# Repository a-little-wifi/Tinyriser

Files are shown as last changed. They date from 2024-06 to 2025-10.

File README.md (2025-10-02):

# TinyRiser
Cooler/cuter riser for Lenovo 8th/9th gen Tiny5 PCs

Exposes the x8 and x4 PCIe links in the riser slot, in the form of a PCIe x16 slot and an m.2 slot.

The x8 link comes from the CPU and was meant for GPU equipped models, while the x4 link comes from the PCH and was meant for the Thunderbolt and NIC equipped models. Lenovo made two different risers for these configurations, only using one link at a time, but this riser gives you both PCIe links at once! The two links are completely independent and are able to function at the same time.

Using this riser, you can install a low profile PCIe card just as you can with the stock risers, and add an extra M.2 NVMe SSD in addition to the onboard ones. The SSD is tucked away near the front of the machine, plugged into a right angle M-key M.2 slot that holds the SSD firmly in place. Due to an unfortunate non-removable standoff placement on the motherboard, only 2230, 2242 and 2260 size SSDs fit comfortably. It is possible to get a 2280 drive to fit if you try hard enough, but the fit will be suboptimal.

Doesn't require any modifications to the motherboard, just works plug and play (no bifurcation/lane reversal).

I've successfully tested this riser on my own M720q where it works 100% perfectly with x1, x4, x8 and x16 cards, and it will work just as well on the other machines that share this motherboard, the M920q, M920x and P330 Tiny.

Note that the M.2 slot only supports PCIe NVMe M-key or B+M-key drives, not SATA ones.

The v2 design includes a fan header that can be used in multiple ways:

- 12V no PWM
- 12V with PWM
- Voltage controlled speed

The last 2 modes require some kind of fan controller module plugged into the provided header. This has not been designed yet, but the possibility exists.

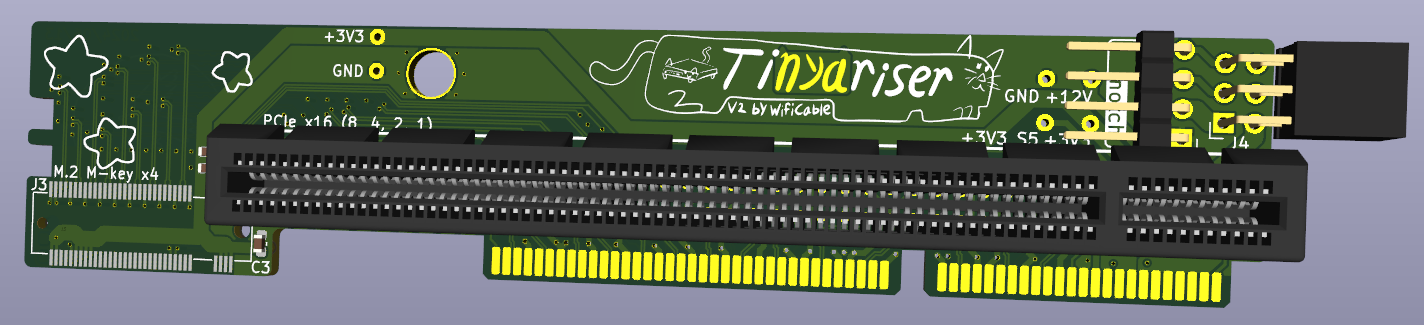
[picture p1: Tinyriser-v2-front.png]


> Front side render of the PCB. I don't have a 3D model for the m.2 slot but you can see the footprint for it

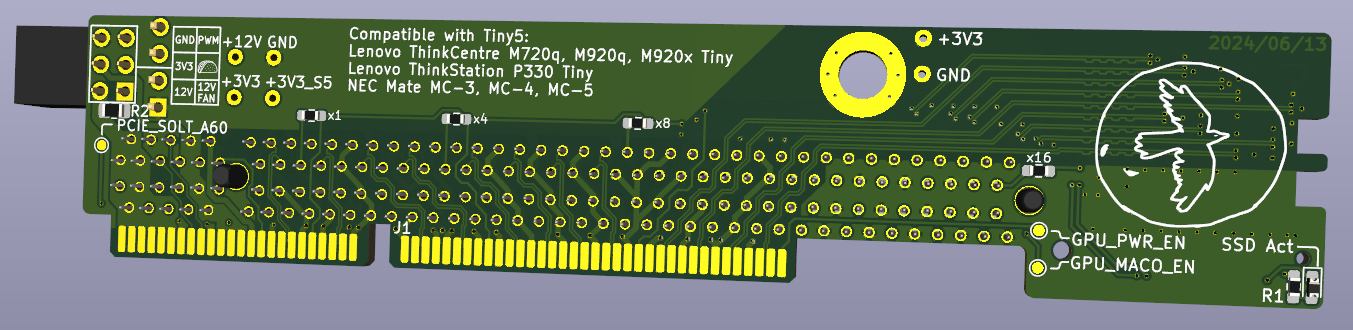
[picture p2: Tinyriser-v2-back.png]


> Back side render of the PCB.

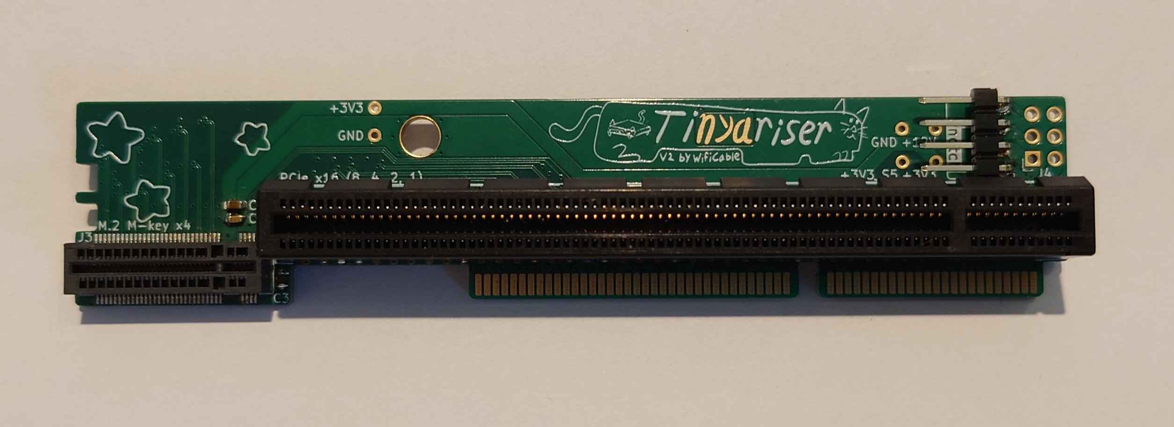
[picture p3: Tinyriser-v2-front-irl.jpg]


> Front of it but in real life

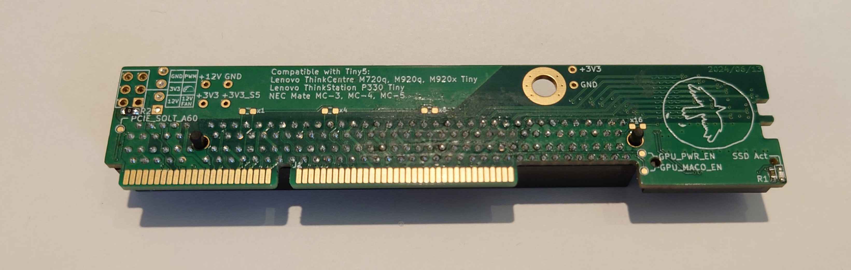
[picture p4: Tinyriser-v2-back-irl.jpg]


> Back of it but also in real life

Compatible with M720q, M920q, M920x and P330 Tiny, as well as the NEC rebranded versions of those.  
**Don't stick it in an M910x or P320 Tiny, it will physically fit but the pinout is not compatible.**

Currently in version 2.1

## Parts list:
| part | model | link |
|---|---|---|
| PCIe slot | UMAX 3183-10203P1T | https://www.lcsc.com/product-detail/Card-Edge-Connectors_UMAX-3183-10203P1T_C404116.html |
| Vertical M-key slot | Lotes APCI0110-P001A | (available on aliexpress) |
| Screwpost | YIYUAN SMTSOM340BTR  | https://www.lcsc.com/product-detail/Other-nuts_YIYUAN-SMTSOM340BTR_C5301786.html |

## JLC PCB ordering details:

Please use the files from the v2.1 release, the main repo might be in the middle of version changes

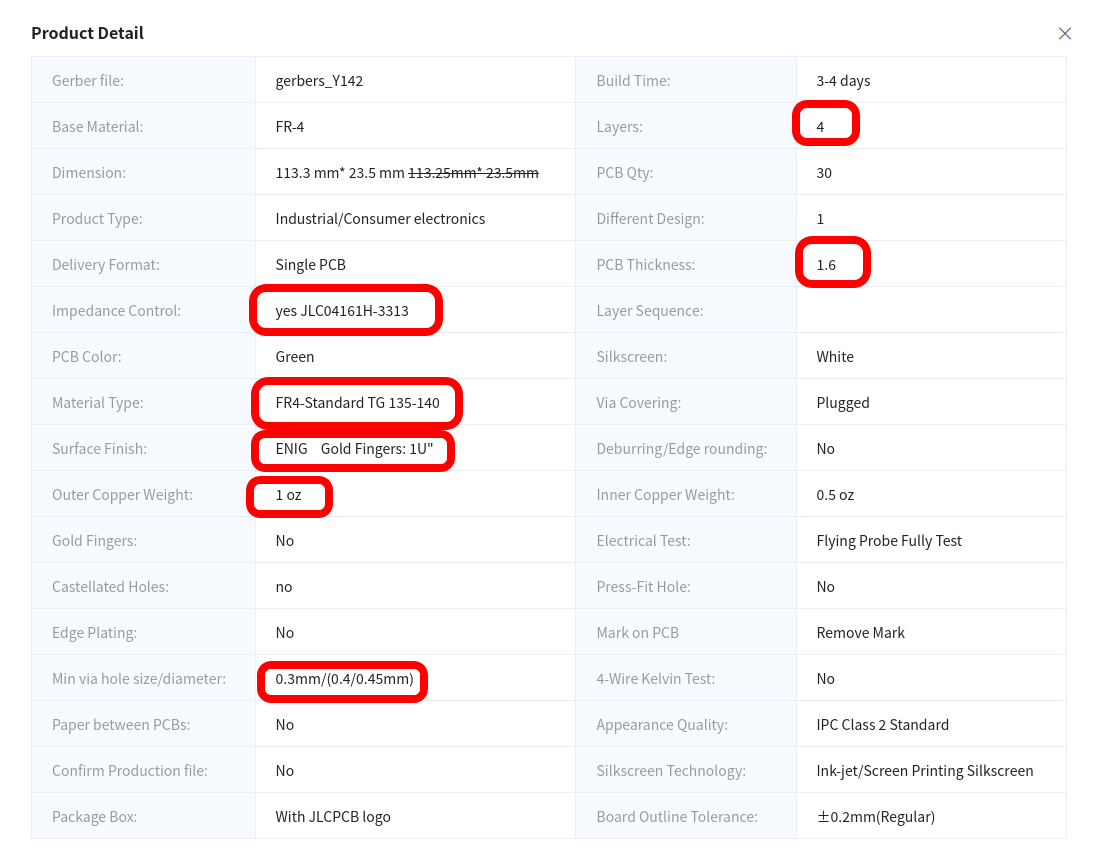
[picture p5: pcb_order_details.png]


> Screenshot of the JLC PCB order settings used for TinyRiser

https://github.com/a-little-wifi/Tinyriser/assets/139929586/086969f3-38e6-4d3a-b0c4-e65df9add474  
> unmute it

# Attribution
If you distribute this design or use this design to create a derivative design, you must keep attribution to this original design, in addition to following the terms in the license

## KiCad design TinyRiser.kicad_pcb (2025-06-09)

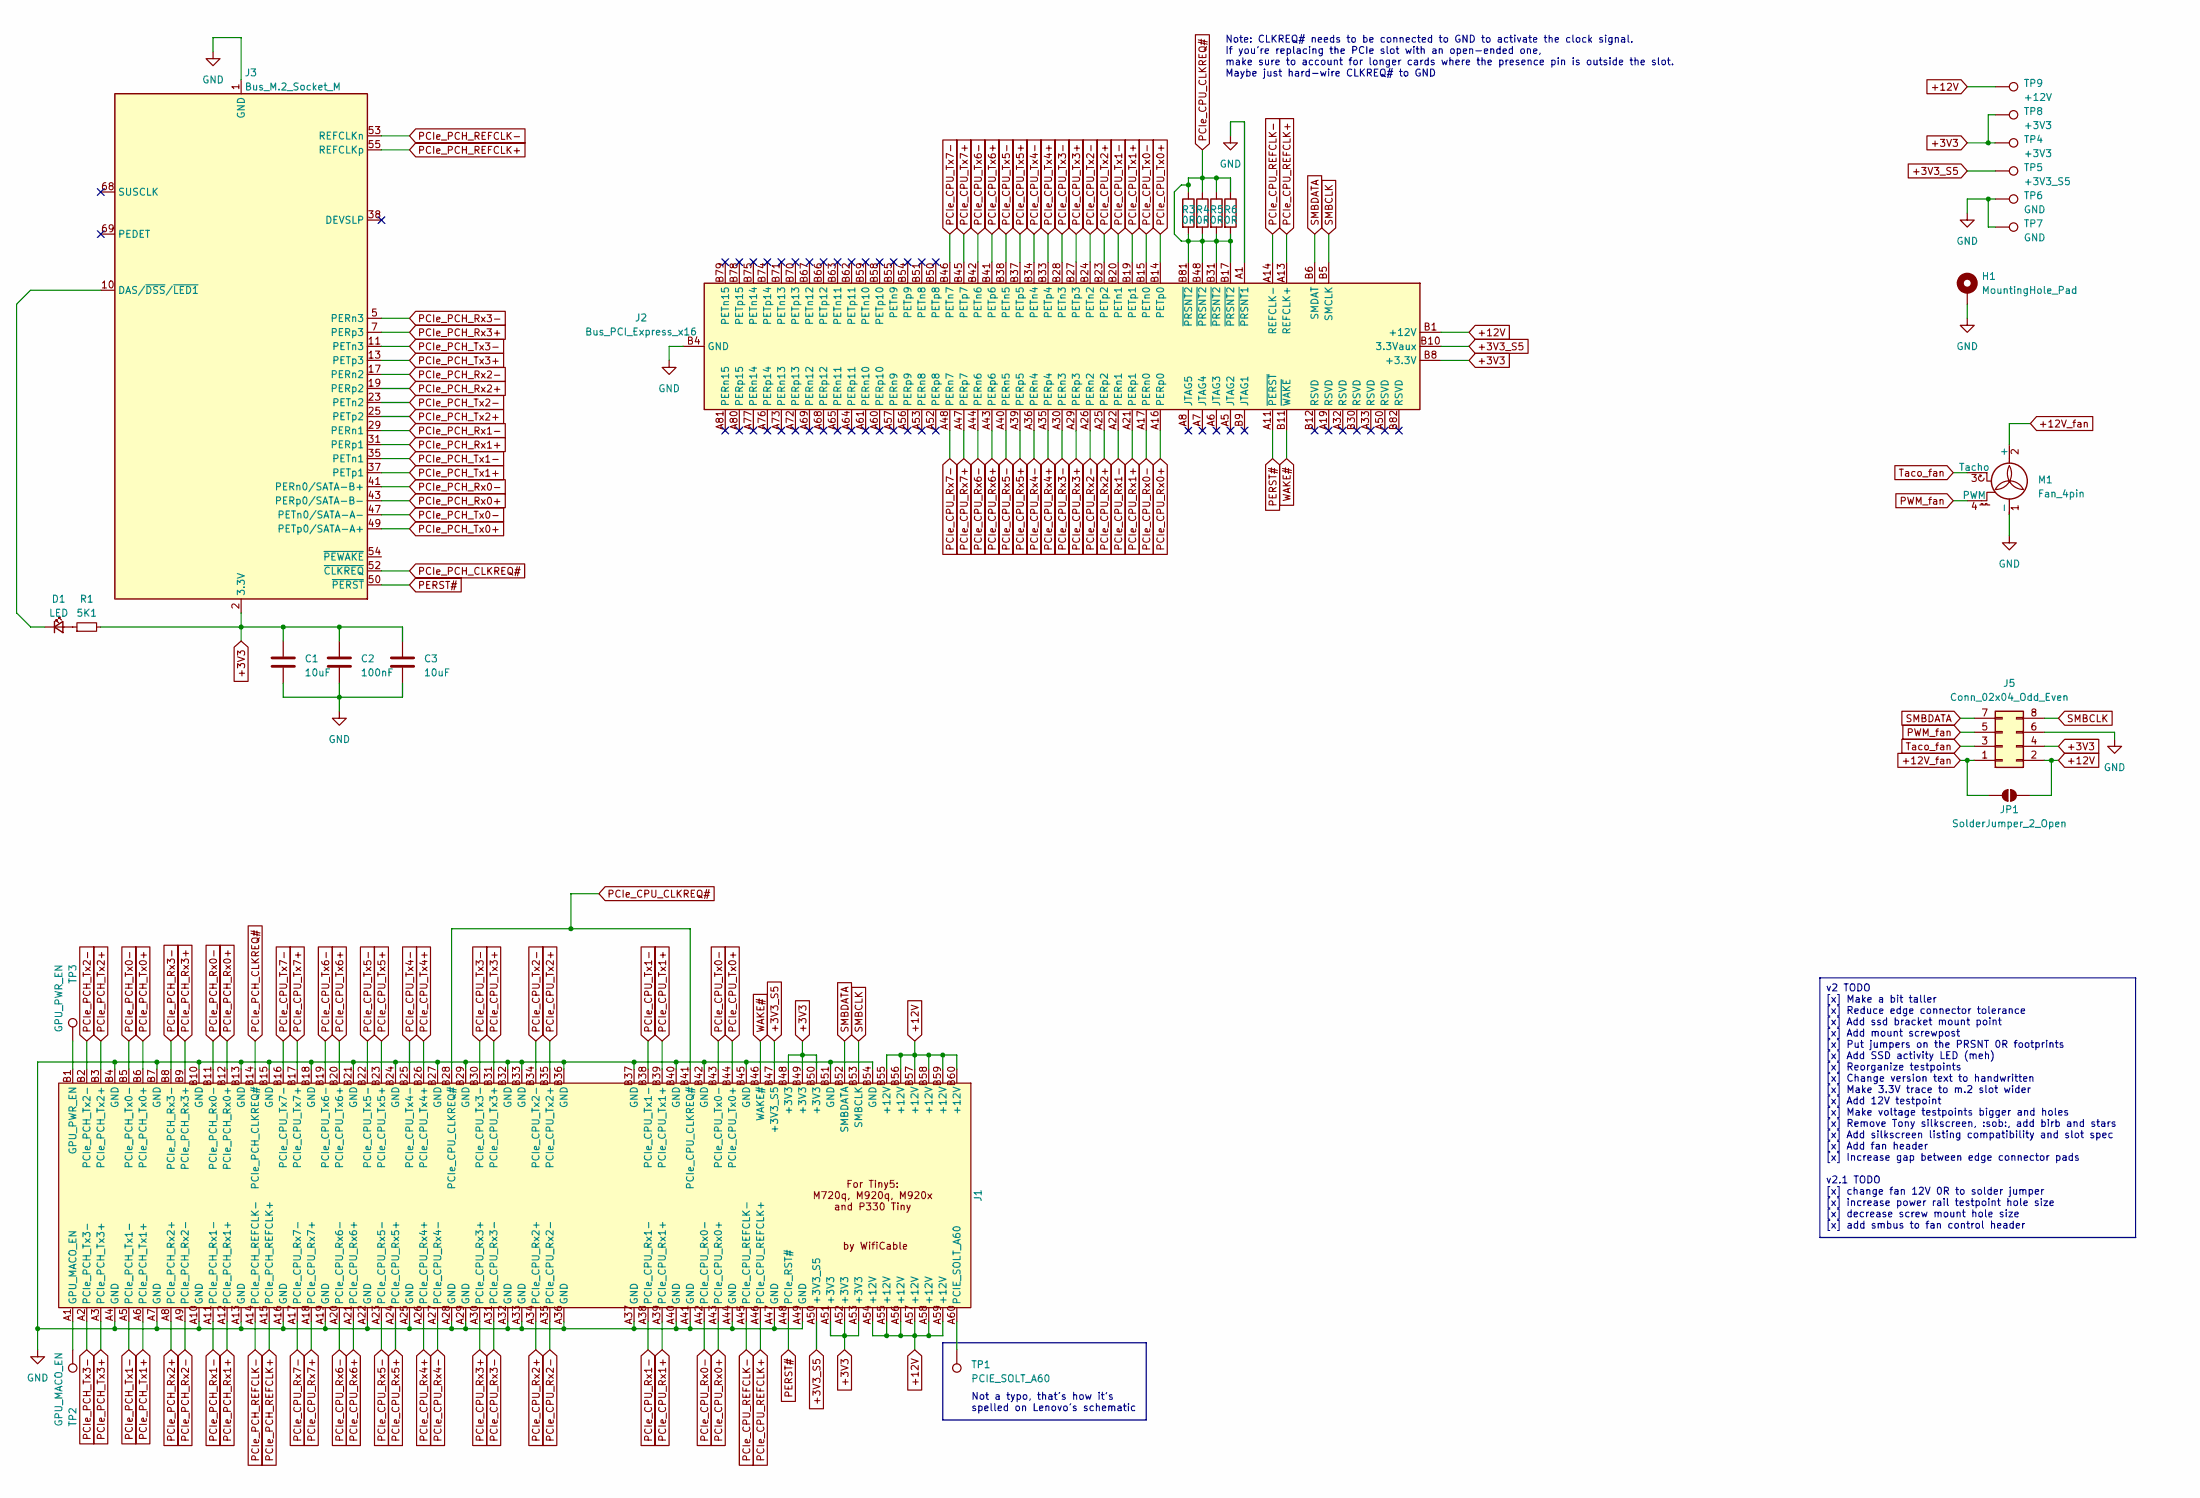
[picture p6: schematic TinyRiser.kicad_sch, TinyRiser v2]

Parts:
C1, C3: 10uF; C_0603_1608Metric
C2: 100nF; C_0603_1608Metric
D1: LED; D_0603_1608Metric_Pad1.05x0.95mm_HandSolder
H1: MountingHole_Pad; MountingHole_4.3mm_M4_ISO7380_Pad_TopOnly
J1: TinyRiser
J2: Bus_PCI_Express_x16; PCIe_x16_tht
J3: Bus_M.2_Socket_M; M.2_NGFF_KeyM_H5.3_Vertical
J5: Conn_02x04_Odd_Even; PinSocket_2x04_P2.54mm_Horizontal
JP1: SolderJumper_2_Open; SolderJumper-2_P1.3mm_Open_TrianglePad1.0x1.5mm
M1: Fan_4pin; PinHeader_1x04_P2.54mm_Horizontal
R1: 5K1; R_0603_1608Metric_Pad0.98x0.95mm_HandSolder
R3, R4, R5, R6: 0R; R_0603_1608Metric_Pad0.98x0.95mm_HandSolder
TP1: PCIE_SOLT_A60; TestPoint_Pad_D1.0mm
TP2: GPU_MACO_EN; TestPoint_Pad_D1.0mm
TP3: GPU_PWR_EN; TestPoint_Pad_D1.0mm
TP4, TP8: +3V3; TestPoint_THTPad_D1.5mm_Drill0.7mm
TP5: +3V3_S5; TestPoint_THTPad_D1.5mm_Drill0.7mm
TP6, TP7: GND; TestPoint_THTPad_D1.5mm_Drill0.7mm
TP9: +12V; TestPoint_THTPad_D1.5mm_Drill0.7mm

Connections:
+3V3: C1.1, C2.1, C3.1, J1.A51 (+3V3), J1.A52 (+3V3), J1.A53 (+3V3), J1.B48 (+3V3), J1.B49 (+3V3), J1.B50 (+3V3), J2.A9 (+3.3V), J2.A10 (+3.3V), J2.B8 (+3.3V), J3.2 (3.3V), J3.4 (3.3V), J3.12 (3.3V), J3.14 (3.3V), J3.16 (3.3V), J3.18 (3.3V), J3.70 (3.3V), J3.72 (3.3V), J3.74 (3.3V), J5.4, R1.2, TP4.1, TP8.1
+3V3_S5: J1.A50 (+3V3_S5), J1.B47 (+3V3_S5), J2.B10 (3.3Vaux), TP5.1
+12V: J1.A54 (+12V), J1.A55 (+12V), J1.A56 (+12V), J1.A57 (+12V), J1.A58 (+12V), J1.A59 (+12V), J1.B55 (+12V), J1.B56 (+12V), J1.B57 (+12V), J1.B58 (+12V), J1.B59 (+12V), J1.B60 (+12V), J2.A2 (+12V), J2.A3 (+12V), J2.B1 (+12V), J2.B2 (+12V), J2.B3 (+12V), J5.2, JP1.2 (B), TP9.1
+12V_fan: J5.1, JP1.1 (A), M1.2 (+)
GND: C1.2, C2.2, C3.2, H1.1, J1.A4 (GND), J1.A7 (GND), J1.A10 (GND), J1.A13 (GND), J1.A16 (GND), J1.A19 (GND), J1.A22 (GND), J1.A25 (GND), J1.A28 (GND), J1.A29 (GND), J1.A32 (GND), J1.A33 (GND), J1.A36 (GND), J1.A37 (GND), J1.A40 (GND), J1.A41 (GND), J1.A44 (GND), J1.A47 (GND), J1.A49 (GND), J1.B4 (GND), J1.B7 (GND), J1.B10 (GND), J1.B13 (GND), J1.B15 (GND), J1.B18 (GND), J1.B21 (GND), J1.B24 (GND), J1.B27 (GND), J1.B29 (GND), J1.B32 (GND), J1.B33 (GND), J1.B36 (GND), J1.B37 (GND), J1.B40 (GND), J1.B42 (GND), J1.B45 (GND), J1.B51 (GND), J1.B54 (GND), J2.A1 (~PRSNT1), J2.A4 (GND), J2.A12 (GND), J2.A15 (GND), J2.A18 (GND), J2.A20 (GND), J2.A23 (GND), J2.A24 (GND), J2.A27 (GND), J2.A28 (GND), J2.A31 (GND), J2.A34 (GND), J2.A37 (GND), J2.A38 (GND), J2.A41 (GND), J2.A42 (GND), J2.A45 (GND), J2.A46 (GND), J2.A49 (GND), J2.A51 (GND), J2.A54 (GND), J2.A55 (GND), J2.A58 (GND), J2.A59 (GND), J2.A62 (GND), J2.A63 (GND), J2.A66 (GND), J2.A67 (GND), J2.A70 (GND), J2.A71 (GND), J2.A74 (GND), J2.A75 (GND), J2.A78 (GND), J2.A79 (GND), J2.A82 (GND), J2.B4 (GND), J2.B7 (GND), J2.B13 (GND), J2.B16 (GND), J2.B18 (GND), J2.B21 (GND), J2.B22 (GND), J2.B25 (GND), J2.B26 (GND), J2.B29 (GND), J2.B32 (GND), J2.B35 (GND), J2.B36 (GND), J2.B39 (GND), J2.B40 (GND), J2.B43 (GND), J2.B44 (GND), J2.B47 (GND), J2.B49 (GND), J2.B52 (GND), J2.B53 (GND), J2.B56 (GND), J2.B57 (GND), J2.B60 (GND), J2.B61 (GND), J2.B64 (GND), J2.B65 (GND), J2.B68 (GND), J2.B69 (GND), J2.B72 (GND), J2.B73 (GND), J2.B76 (GND), J2.B77 (GND), J2.B80 (GND), J3.1 (GND), J3.3 (GND), J3.9 (GND), J3.15 (GND), J3.21 (GND), J3.27 (GND), J3.33 (GND), J3.39 (GND), J3.45 (GND), J3.51 (GND), J3.57 (GND), J3.71 (GND), J3.73 (GND), J3.75 (GND), J5.6, M1.1 (-), TP6.1, TP7.1
unnamed: D1.2 (A), R1.1
unnamed: D1.1 (K), J3.10 (DAS/~DSS/~LED1)
unnamed: J1.A1 (GPU_MACO_EN), TP2.1
unnamed: J1.B1 (GPU_PWR_EN), TP3.1
unnamed: J1.A60 (PCIE_SOLT_A60), TP1.1
PCIe_CPU_CLKREQ#: J1.B28 (PCIe_CPU_CLKREQ#), J1.B41 (PCIe_CPU_CLKREQ#), J2.B17 (~PRSNT2), J2.B31 (~PRSNT2), J2.B48 (~PRSNT2), J2.B81 (~PRSNT2), R3.1, R3.2, R4.1, R4.2, R5.1, R5.2, R6.1, R6.2
PCIe_CPU_REFCLK+: J1.A46 (PCIe_CPU_REFCLK+), J2.A13 (REFCLK+)
PCIe_CPU_REFCLK-: J1.A45 (PCIe_CPU_REFCLK-), J2.A14 (REFCLK-)
PCIe_CPU_Rx0+: J1.A43 (PCIe_CPU_Rx0+), J2.A16 (PERp0)
PCIe_CPU_Rx0-: J1.A42 (PCIe_CPU_Rx0-), J2.A17 (PERn0)
PCIe_CPU_Rx1+: J1.A39 (PCIe_CPU_Rx1+), J2.A21 (PERp1)
PCIe_CPU_Rx1-: J1.A38 (PCIe_CPU_Rx1-), J2.A22 (PERn1)
PCIe_CPU_Rx2+: J1.A34 (PCIe_CPU_Rx2+), J2.A25 (PERp2)
PCIe_CPU_Rx2-: J1.A35 (PCIe_CPU_Rx2-), J2.A26 (PERn2)
PCIe_CPU_Rx3+: J1.A30 (PCIe_CPU_Rx3+), J2.A29 (PERp3)
PCIe_CPU_Rx3-: J1.A31 (PCIe_CPU_Rx3-), J2.A30 (PERn3)
PCIe_CPU_Rx4+: J1.A26 (PCIe_CPU_Rx4+), J2.A35 (PERp4)
PCIe_CPU_Rx4-: J1.A27 (PCIe_CPU_Rx4-), J2.A36 (PERn4)
PCIe_CPU_Rx5+: J1.A24 (PCIe_CPU_Rx5+), J2.A39 (PERp5)
PCIe_CPU_Rx5-: J1.A23 (PCIe_CPU_Rx5-), J2.A40 (PERn5)
PCIe_CPU_Rx6+: J1.A21 (PCIe_CPU_Rx6+), J2.A43 (PERp6)
PCIe_CPU_Rx6-: J1.A20 (PCIe_CPU_Rx6-), J2.A44 (PERn6)
PCIe_CPU_Rx7+: J1.A18 (PCIe_CPU_Rx7+), J2.A47 (PERp7)
PCIe_CPU_Rx7-: J1.A17 (PCIe_CPU_Rx7-), J2.A48 (PERn7)
PCIe_CPU_Tx0+: J1.B44 (PCIe_CPU_Tx0+), J2.B14 (PETp0)
PCIe_CPU_Tx0-: J1.B43 (PCIe_CPU_Tx0-), J2.B15 (PETn0)
PCIe_CPU_Tx1+: J1.B39 (PCIe_CPU_Tx1+), J2.B19 (PETp1)
PCIe_CPU_Tx1-: J1.B38 (PCIe_CPU_Tx1-), J2.B20 (PETn1)
PCIe_CPU_Tx2+: J1.B35 (PCIe_CPU_Tx2+), J2.B23 (PETp2)
PCIe_CPU_Tx2-: J1.B34 (PCIe_CPU_Tx2-), J2.B24 (PETn2)
PCIe_CPU_Tx3+: J1.B31 (PCIe_CPU_Tx3+), J2.B27 (PETp3)
PCIe_CPU_Tx3-: J1.B30 (PCIe_CPU_Tx3-), J2.B28 (PETn3)
PCIe_CPU_Tx4+: J1.B26 (PCIe_CPU_Tx4+), J2.B33 (PETp4)
PCIe_CPU_Tx4-: J1.B25 (PCIe_CPU_Tx4-), J2.B34 (PETn4)
PCIe_CPU_Tx5+: J1.B23 (PCIe_CPU_Tx5+), J2.B37 (PETp5)
PCIe_CPU_Tx5-: J1.B22 (PCIe_CPU_Tx5-), J2.B38 (PETn5)
PCIe_CPU_Tx6+: J1.B20 (PCIe_CPU_Tx6+), J2.B41 (PETp6)
PCIe_CPU_Tx6-: J1.B19 (PCIe_CPU_Tx6-), J2.B42 (PETn6)
PCIe_CPU_Tx7+: J1.B17 (PCIe_CPU_Tx7+), J2.B45 (PETp7)
PCIe_CPU_Tx7-: J1.B16 (PCIe_CPU_Tx7-), J2.B46 (PETn7)
PCIe_PCH_CLKREQ#: J1.B14 (PCIe_PCH_CLKREQ#), J3.52 (~CLKREQ)
PCIe_PCH_REFCLK+: J1.A15 (PCIe_PCH_REFCLK+), J3.55 (REFCLKp)
PCIe_PCH_REFCLK-: J1.A14 (PCIe_PCH_REFCLK-), J3.53 (REFCLKn)
PCIe_PCH_Rx0+: J1.B12 (PCIe_PCH_Rx0+), J3.43 (PERp0/SATA-B-)
PCIe_PCH_Rx0-: J1.B11 (PCIe_PCH_Rx0-), J3.41 (PERn0/SATA-B+)
PCIe_PCH_Rx1+: J1.A12 (PCIe_PCH_Rx1+), J3.31 (PERp1)
PCIe_PCH_Rx1-: J1.A11 (PCIe_PCH_Rx1-), J3.29 (PERn1)
PCIe_PCH_Rx2+: J1.A8 (PCIe_PCH_Rx2+), J3.19 (PERp2)
PCIe_PCH_Rx2-: J1.A9 (PCIe_PCH_Rx2-), J3.17 (PERn2)
PCIe_PCH_Rx3+: J1.B9 (PCIe_PCH_Rx3+), J3.7 (PERp3)
PCIe_PCH_Rx3-: J1.B8 (PCIe_PCH_Rx3-), J3.5 (PERn3)
PCIe_PCH_Tx0+: J1.B6 (PCIe_PCH_Tx0+), J3.49 (PETp0/SATA-A+)
PCIe_PCH_Tx0-: J1.B5 (PCIe_PCH_Tx0-), J3.47 (PETn0/SATA-A-)
PCIe_PCH_Tx1+: J1.A6 (PCIe_PCH_Tx1+), J3.37 (PETp1)
PCIe_PCH_Tx1-: J1.A5 (PCIe_PCH_Tx1-), J3.35 (PETn1)
PCIe_PCH_Tx2+: J1.B3 (PCIe_PCH_Tx2+), J3.25 (PETp2)
PCIe_PCH_Tx2-: J1.B2 (PCIe_PCH_Tx2-), J3.23 (PETn2)
PCIe_PCH_Tx3+: J1.A3 (PCIe_PCH_Tx3+), J3.13 (PETp3)
PCIe_PCH_Tx3-: J1.A2 (PCIe_PCH_Tx3-), J3.11 (PETn3)
PERST#: J1.A48 (PCIe_RST#), J2.A11 (~PERST), J3.50 (~PERST)
PWM_fan: J5.5, M1.4 (PWM)
SMBCLK: J1.B53 (SMBCLK), J2.B5 (SMCLK), J5.8
SMBDATA: J1.B52 (SMBDATA), J2.B6 (SMDAT), J5.7
Taco_fan: J5.3, M1.3 (Tacho)
WAKE#: J1.B46 (WAKE#), J2.B11 (~WAKE)

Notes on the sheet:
v2 TODO [x] Make a bit taller [x] Reduce edge connector tolerance [x] Add ssd bracket mount point [x] Add mount screwpost [x] Put jumpers on the PRSNT 0R footprints [x] Add SSD activity LED (meh) [x] Reorganize testpoints [x] Change version text to handwritten [x] Make 3.3V trace to m.2 slot wider 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
Not a typo, that's how it's spelled on Lenovo's schematic
Note: CLKREQ# needs to be connected to GND to activate the clock signal. If you're replacing the PCIe slot with an open-ended one, make sure to account for longer cards where the presence pin is outside the slot. Maybe just hard-wire CLKREQ# to GND

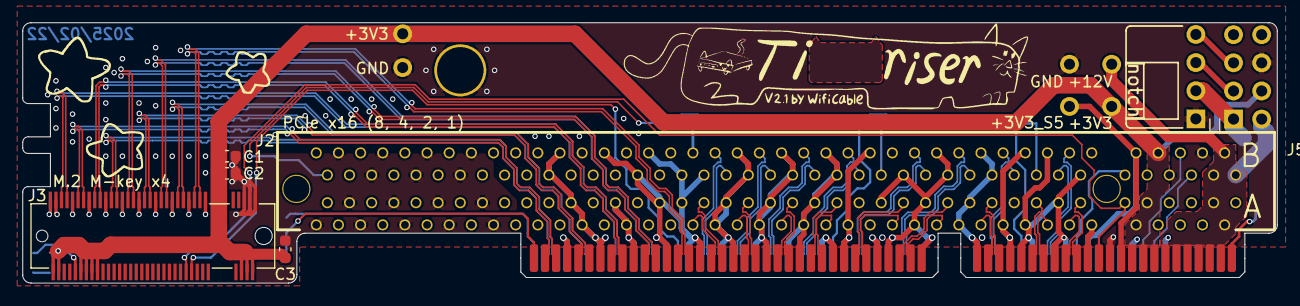
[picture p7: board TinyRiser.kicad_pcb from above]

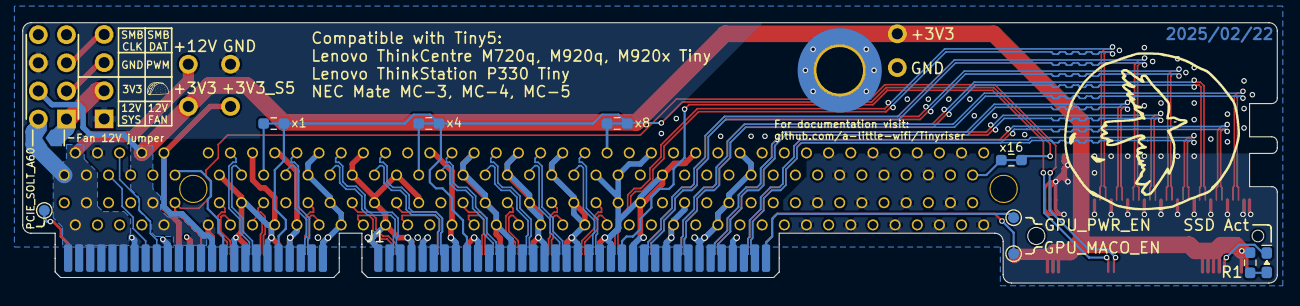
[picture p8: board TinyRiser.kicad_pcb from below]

Board: 4 copper layers, 113.2 x 23.5 mm, 25 parts (12 on the bottom side), 70 nets.

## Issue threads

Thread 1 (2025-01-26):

Where can I get one please?

huss79, 2025-01-26:
Hi is the also plug & play like your v1 and were can I get one please. It looks very interesting. I own a p330 tiny with 165w I think power adaptor. Currently have the nic\graphic low profile card. But would be interested in this if it works with my PC. Looking to add m.2 nvme and NIC if possible. Thanks.

lmbacelar, 2025-02-26:
Hi there !
Can you ship 3 of these to Portugal?
What is the price for the riser?
Thanks!

a-little-wifi, 2025-03-05:
Hi, sorry for the late reply, been busy. This is plug and play, also with the P330 Tiny yes. Unfortunately I don't currently have any more of these boards in stock, hoping to order a new batch soon. If you want I'll let you know once I have more available, or you can order the PCBs and assemble your own using the files in this repository (use the ones from the v2 release in the sidebar)

maldworth, 2025-03-09:
Wow thanks, it's great you have instructions for ordering ourselves on jlc pcb. I'm curious, is it possible to have the vertical m.2 and pcie slots already installed and assembled by them through their ordering process?

It's mentioned in a similar fashion here:
https://github.com/j4cbo/tiny5-m2-riser/blob/main/pcb-v2/README.md
where he even says the m.2 is often out of stock, but you can use their global sourcing tool to order them.

huss79, 2025-03-09:
> Hi, sorry for the late reply, been busy. This is plug and play, also with the P330 Tiny yes. Unfortunately I don't currently have any more of these boards in stock, hoping to order a new batch soon. If you want I'll let you know once I have more available, or you can order the PCBs and assemble your own using the files in this repository (use the ones from the v2 release in the sidebar)

Hi yes please let me know when you have more in stock.. thanks for the reply..

s0undy, 2025-07-04:
Do you have any plans to offer assembled kits for sale in the near future, or know anyone else that does? I would be interested in purchasing three, as I'm not very comfortable with soldering them myself. 😊

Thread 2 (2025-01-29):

Suggestion:- relocate R1, R2 and D1 to top side of board

westy8563, 2025-01-29:
This is a great looking project, many thanks for your efforts putting it together.

I'm looking at getting some boards manufactured and partially assembled by JLCPCB. To reduce the cost of assembly it would be beneficial to have R1, R2 and D1 moved to the top surface so that everything is on the one side.

I appreciate the LED can just be omitted, but it's a nice touch. Perhaps including placements for both a front and / or rear mounted LED could be a neat solution?

Looking at your irl photo it looks like R2 is definitely required? If so, could this be relocated to the top surface? If not, then I'll leave it out :)

Many thanks!

a-little-wifi, 2025-03-05:
Sorry for the wait, been a bit busy. Glad you like my project! This is a good idea, I never considered automated assembly by the PCB fab. Technically you can leave all of them out, R2 is only needed to bring power to the fan header, and R1 and D1 are for the LED. Without these parts both PCIe slots will still work fine.
In the mean time, I've updated the design to v2.1 (but haven't ordered boards for that version yet, so technically untested), where I replaced R2 with a solderable jumper, making assembly easier. There isn't really any space to neatly move the LED to the front side, so that'll have to remain a manual assembly option.
Hope this helps!

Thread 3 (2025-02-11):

Enhancement: add molex header

Chuckame, 2025-02-11:
Hey,

This design is in my opinion the most advanced and versatile custom riser. But when coming to my new project, it's missing a molex header: I want to make a mini full ssd mini nas, and thanks to the pcie spec, we can go up to 75 watts. Let's say with a fan and an hba or a classical sata extender, we still have around 60w available, which would easily fit 4 ssd sata drives (after roughly 33% of convertion loss 40w, 16w in 5v) pulling 3w max each!

I know the pci spec only provides 12v and 3.3v, while ssd requires 5v line. Do you think it's achievable to have this 12->5v converter on the board, or it's too difficult, and stealing the 5v live from a capacitor placeholder on the board is better?

thinrope, 2025-02-26:
While 12V->5V conversion may sound "trivial", there is a lot that can go wrong and adding say a voltage regulator will definitely add noise. Given that few people will actually use it, I'd suggest that you get a dedicated 12->5V solution, enclosed in a metal shield to try to minimize noise.

a-little-wifi, 2025-03-05:
Hi @Chuckame, I'm glad you like my riser! As @thinrope says, adding a 12V to 5V regulator is not a simple task, and not something I have experience or confidence to make reliable at this point in time. You would have to wire up an external 12V to 5V module to the header already present on the riser, or use the 5V point available on the mainboard.

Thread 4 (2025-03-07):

Clarification of P320 compatibility

jefhef, 2025-03-07:
The README states the M910x or P320 Tiny are mechanically compatible with the riser but the pinout isn't. Does that just mean the pinout for the M.2 slot isn't compatible or would that include the PCIe slot too. I currently have some basic no-name AliExpress risers and they do work in both my P320 and M920x to support a 10gigE Mellanox card. If your riser was used in a P320 as _just_ a PCIe riser with no NVMe drive would that work? or is the riser just full stop incompatible with the P320? If so any insight on what was done differently relative to the generic Chinese risers? Even if just the PCIe slot works and the M.2 slot was off limits on those models it would still be great having the fan header to provide some extra cooling for the NIC.

I also wanted to just thank you for sharing your design publicly. I actually just received some boards and will be jumping in the deep end in trying to assemble a few for myself as an eventual upgrade to my generic AliExpress risers.

a-little-wifi, 2025-03-07:
Hi, fun question you got here. It's slightly complicated, technically they are partially compatible. The pinouts of the Tiny4 and Tiny5 riser slots are the same up to the 5th PCIe lane, after that it shifts a bit, and of course Tiny4 doesn't include the PCIe lanes for the M.2 slot at all. This means that in the best case, you will get a PCIe x4 link on the main PCIe slot, which is probably what you're getting on at least one of your machines you're using the same riser in.
The only thing I'm not sure about with this is how bad it is for the rest of the pins, as using a Tiny5 riser in a Tiny4 machine with a PCIe x8 card installed will short parts of some of the PCIe lanes to ground. This might be perfectly fine but I wouldn't recommend running it like that. I've attached some screenshots of the Tiny4 vs Tiny5 riser slot pinouts below.

Also cool to hear you made you placed your own PCB order, you're the first one I've heard who has actually gone through with it. Good luck with the assembly!
One question though, did you use the files from the repo directly or did you use the tinyriser v2 release in the sidebar? Depending on when you downloaded the files they might be in the middle of changes between revisions as I've been working on the updated v2.1 design recently.

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

jefhef, 2025-03-08:
You made me nervous so I had to go verify what files I would have submitted. It looks like I did indeed use the v2 tag and not the mainline trunk. I thought I read some comment somewhere to use the v2 tag if ordering but I don't recall where I got that notion from or if it might have been my own gut feeling. I assume you'd likely tag the next design as v2.1 when you are finished.

The cards I have are Mellanox MCX311A which are single port SFP+ PCIe x4 NICs so maybe that might also work in my favor? Dual port NICs just seemed overkill since I just looking to give my Openstack lab's Ceph network a little extra bandwidth than the built in 1gigE interface, I don't care about redundancy for this. Plus the single port NIC is a little more compact than the dual port Intel NICs have laying around. and the p320s are just the controllers so the loss of the NMEe is no big deal. the m920x is where the extra slot will come in handy.

I like pushing a bit out of my comfort zone regularly. If I was younger, I'd likely be classified as kids like to say, a bit of a try hard. Learning to solder has been on my TODO list for a a long time and I feel this just might be the thing to push me to into motion. I was excited to figured out enough on how to even order the boards. I'd never even heard of KiCAD before this :) Even though someone else did all the engineering work, It was quite satisfying just have successfully ordered the PCB and to see it in my hand.

There are some simpler things I have to use as practice tasks before I actually try my hand at this but wanted to order them before tariffs and other BS likely make it cost prohibitive for the DIY tinkerer types. I'm coming into this as a total newb so if you don't mind a few more questions. When you assembled yours did you assemble the side with the M.2 connector using an oven? and then then solder the other side by hand? You provide some links to sources for a few of the parts, you have any suggestion/recommendation on where sources for the other components?

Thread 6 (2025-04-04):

Recommended version

nesanakin, 2025-04-04:
Hi!

I'm about to put in a JLC PCB order for a few of these risers. Is v2 still the recommended version? I see there's been some recent work done toward a v2.1, is that ready to go? Does it have any impactful changes over v2?

Thanks! I'm excited to use these risers, it seems like a great design.

a-little-wifi, 2025-04-04:
Hi, if you want to be sure I would recommend you take v2. v2.1 should be fine in theory, but I haven't placed the pcb order for them myself yet (waiting to combine with tiny6 riser order) so I can't guarantee it's all good.
Changes are pretty much what's listed in the commits: a minor silkscreen change to clarify LED polarity, adding smbus to the fan control header and changing the fan header 12V 0R footprint to a solderable jumper.
In theory none of that should break anything, so I think the risk in trying v2.1 is pretty low, you could get yourself a v2.1 before even I get my hands on them lmao.
And thanks, glad you like my design! Let me know if there's anything else you run into.

nesanakin, 2025-04-05:
Cool, thanks. I'm up for trying v2.1. The per-board cost is so cheap, if I order a bigger batch do you want me to mail you the extras?

calebfloyd, 2025-04-07:
I'm also planing to put in a JLC PCB order. Do they need only the .kincad_pcb file, or do they also need the .kincad_sch and .kincad_pro files? Thanks for making this puclically available!

a-little-wifi, 2025-04-08:
@nesanakin if you have any leftovers you won't be using, I certainly won't say no to receiving them, that would be quite nice. Thank you for offering.
For the bracket, I didn't really have anything super worked out yet, but figured adding the notches for it was better than not doing it lol. Here's a very crappy sketch of roughly what I had in mind, if it makes any sense:
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

@calebfloyd You'll have to use KiCad to export the project as gerber files according to JLCPCB's instructions, then you can upload the gerbers to JLC's website and order using the settings given in the readme.

nesanakin, 2025-04-09:
I ordered 25 of v2.1 with the front LED and they just shipped. Hopefully everything goes smoothly with the US tariffs and other nonsense. I'll post back when they arrive and I can get some mailed out to you.

@calebfloyd if you want a couple I'm happy to send some your way as well.

calebfloyd, 2025-04-09:
@nesanakin I'd love 3 or 4 when they come in. Just let me know when, and how much to cover costs and shipping.

geekifier, 2025-04-09:
@nesanakin I might possibly be interested in three of those as well, if you have any left.

a-little-wifi, 2025-04-10:
Ohh you went with the front led version lol, that'll be interesting. I wasn't planning to ever order some of those myself, those are mostly meant so the fab can assemble them single sided. Did you order with assembly? Either way would love to see how they turn out and we can sort out some details later.

nesanakin, 2025-04-10:
@a-little-wifi well, my original intent was to get them assembled, but it was more than I wanted to pay so I just got the boards and the parts separately 😆. The front LED version looked electrically identical to the regular version and it seems like a more useful LED placement anyways so I stuck with it. I'll be the guinea pig to make sure it all works!

a-little-wifi, 2025-04-14:
Electrically the front led one is identical yeah lol. To me the LED on the back made more sense since it shines through the vent on the side of the case, but maybe the front version is visible through the front panel.

nesanakin, 2025-04-14:
Oh that's cool, I didn't realize it was aligned to shine through the side. Oh well!

Here's my parts list from Mouser & DigiKey if it's helpful for anyone. I didn't bother with the pin headers but they should be easy to find.

| Designator     | Part                               | Qty | Part #               | Link                                                                                            |
| -------------- | ---------------------------------- | --- | -------------------- | ----------------------------------------------------------------------------------------------- |
| R1             | Resistor 0603 5k1 1%               | 1   | RC0603FR-7W5K1L      | [Mouser](https://www.mouser.com/ProductDetail/603-RC0603FR-7W5K1L)                              |
| R3, R4, R5, R6 | Resistor 0603 0R 1%                | 4   | RC0603FR-100RL       | [Mouser](https://www.mouser.com/ProductDetail/603-RC0603FR-100RL)                               |
| C1, C3         | Capacitor 0603 10µF                | 2   | C1608X5R0J106K080AB  | [Mouser](https://www.mouser.com/ProductDetail/810-C1608X5R0J106K)                               |
| C2             | Capacitor 0603 100nF               | 1   | MSASH168SB5104KTNA01 | [Mouser](https://www.mouser.com/ProductDetail/963-MSASH168SB5104KT)                             |
| D1             | LED Green 0603 3.3v 20mA           | 1   | 155060GS73200        | [Mouser](https://www.mouser.com/ProductDetail/710-155060GS73200)                                |
| H1             | Mounting Hole 4.3mm M4             | 1   | SMTSO-M3-4ET         | [Mouser](https://www.mouser.com/ProductDetail/153-SMTSO-M3-4ET)                                 |
| J2             | PCIe Female 164pos 0.039"          | 1   | 10018784-10213TLF    | [DigiKey](https://www.digikey.com/en/products/detail/amphenol-cs-fci/10018784-10213TLF/1002347) |
| J3             | M.2 NGFF M-Key Female 67pos 0.020" | 1   | MDT350M01001VT       | [DigiKey](https://www.digikey.com/en/products/detail/amphenol-cs-fci/MDT350M01001VT/10232903)   |
| J5             | PinSocket_2x04_P2.54mm_Horizontal  | 1   |                      |                                                                                                 |
| M1             | PinHeader_1x04_P2.54mm_Horizontal  | 1   |                      |                                                                                                 |

a-little-wifi, 2025-04-14:
Oh careful, the m.2 slot you listed is not the one that will fit on this pcb, it's listed in the readme as a possibe alternative if sourcing the one from aliexpress is no longer possible, but it'll need the footprint on the PCB to be changed to use it. You also don't need the 0R resistors, those footprints can be left empty.

nesanakin, 2025-04-15:
Ugh. That Amphenol M.2 connector is the only one available from DigiKey or Mouser. I just tried importing the actual footprint of it and, yeah, it's not even close to fitting. C3 would have to be relocated and the PCB would have to be widened. It's good that you clarified the Readme but I feel like it shouldn't even be listed as an alternative. It's too bad because the Amphenol ones have some big ground pads on either side that would probably give it a bit of extra structural support in this application.

Anyways I ordered 75 of the other ones from Aliexpress so if anybody wants me to send those along with the PCBs...

a-little-wifi, 2025-04-15:
Damn, I hope you didn't waste a lot on buying the wrong slots, sorry about this. I agree it might be better to just remove the reference to the alternative slot entirely. I mostly added that there as a note for myself in case the aliexpress one became hard to get.
The Lotes connector from aliexpress is also quite sturdy even without ground pads by the way, it feels really solid on the ones I have soldered on over here.

a-little-wifi, 2025-04-15:
Oh good, that riser does use those slots yeah, glad they can still be used.

nesanakin, 2025-04-21:
I have the boards!

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

They look great. I should have the M.2 connectors by end of this week or early next week. Once I have those I can test the board and then mail them out to whoever is interested.

Jameljami11, 2025-04-21:
This looks great! While I can only speak for myself, I would most definitely be interested! I'm curious what's the process for buying from you once testing is done?

calebfloyd, 2025-04-22:
Looking good. I'm still up for 3 when you you're ready.

nesanakin, 2025-04-22:
@Jameljami11 We can email about specifics and figure out what payment methods we have in common. For bare boards I'll do them at-cost + shipping (it came out to about $2.30/board). I wasn't really planning for it but if anyone wants assembled boards we can talk–I have enough parts.

geekifier, 2025-04-22:
@nesanakin Thanks so much for generously offering these at cost. I am still interested in three bare boards whenever you're ready.

GoldDigger1000, 2025-04-24:
> [@Jameljami11](https://github.com/Jameljami11) We can email about specifics and figure out what payment methods we have in common. For bare boards I'll do them at-cost + shipping (it came out to about $2.30/board). I wasn't really planning for it but if anyone wants assembled boards we can talk–I have enough parts.

Hello, I am interested in two assembled boards

greyleaguemax, 2025-04-27:
Hello nesanakin,

Thanks for your kind offer and also for thinking about the others!

I am interested in 2 or 3 assembled boards, if you have time to assemble them, depending on the price (delivery to Switzerland) .
Otherwise 3 kits will be OK for me, I will try to solder them myself.
Hoping not to make a mess, never soldered smd's, the m.2 connector is the thing worrying me most😬

Hope you can get in touch with me.

nesanakin, 2025-05-07:
🎉 it works! I didn't test the fan headers because I didn't get parts for that, but PCIe, the M.2 slot, and the LED all work without issue.

For anyone interested in boards, email me: kate <at> taproot.mx.

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

nesanakin, 2025-05-09:
@calebfloyd @Jameljami11 @GoldDigger1000 — email me when you can. I'm distributing boards in the order people asked for them, but they are almost all spoken for so I need to confirm exact quantities.

calebfloyd, 2025-05-10:
@nesanakin Email sent. Thanks again!

MatrixTechno, 2025-05-20:
@nesanakin Any chance you have another one left?

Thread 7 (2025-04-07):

Can the translation fit under 10cm?

zanbzx, 2025-04-07:
Can the translation fit under 10cm? JLC offers free samples for boards under 10cm in both dimensions.

a-little-wifi, 2025-04-07:
Looks like it can fit diagonally inside a 10x10cm square yeah. Is that what you wanted to know?
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

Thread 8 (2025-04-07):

Purpose/requirement of R3,R4,R5,R6?

devmills, 2025-04-07:
Hi! First of all thank you very much for this awesome project.
I've just received my boards and connectors and have them soldered up (the m.2 connector was not as hard as it looked, I used drag soldering and some flux).
I realise now that I'm not sure if I need to solder R3,R4,R5 or R6! I see them present in some photos and missing in others. I would very much appreciate any explanation about what they are for and if there's a decision around soldering them or not.

Many thanks again. Can't wait to put these to use.

a-little-wifi, 2025-04-08:
Hi, if you have a v2 or v2.1 board you don't need to solder those 4 resistors. Originally on v1 they were for connecting the PCIe presence detection pins to the CLKREQ pins on the riser slot, and I added 0Ω jumpers to those signals since I wasn't sure if that was the right way to connect things.
I've since found out that that is in fact the correct way to do it and for v2 I added a trace in the resistor footprint to jump the signal by default, but left the footprints so that someone who might want to experiment with them has the possibility (by cutting the trace and having a place to solder a jumper back anyway). You might have seen photos of v1 boards that do have them populated, for those it is necessary.
Also yeah the M.2 slot is surprisingly easy to solder on if you have the right equipment, exactly the way you did it is how I did the first few as well, the rest were done using solder paste and a stencil, that gave a bit more reliable results.
Good luck with them, hope they work well for you!

devmills, 2025-04-08:
Lovely stuff, thank you so much for the reply. I didn't spot the trace in the resistor footprint so that makes perfect sense.
I guess that means my boards are done and ready to test after a quick clean up. Exciting! Thanks again!

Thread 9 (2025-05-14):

Xianyu copies

a-little-wifi, 2025-05-14:
I've encountered a few copies and derivatives of my riser design on Xianyu:

1: https://www.goofish.com/item?id=901949599313
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

> straight up anonymized version of my design with some features removed

2: https://www.goofish.com/item?id=855751027016
https://www.goofish.com/item?id=896278292073

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

> edge connector footprint matches my design visually, where the key between the section goes

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

> literally has a screenshot of my design barely changed in some editor?

3: https://www.goofish.com/item?id=895891277648

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

> another with edge connector visually matching mine

4: https://www.goofish.com/item?id=917456681431

This one seems to be a copy of the first one by a different seller with less info

5: https://www.goofish.com/item?id=915646599780

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

> an even more obvious copy of my design lol, even has a screenshot from the KiCad 3D viewer that's just my project with the logo removed 😔

Number 5 and number 1 appear to have some beef between each other lol. I can't really tell what's going on but from google translations it feels like number 1 is attempting to take credit for the design and is mad that number 5 is also selling it? They keep trying to say number 5 doesn't know how to calculate impedance or something? Whole situation is strange considering neither of them are the ones who actually designed it lmao.

Anyway it's kinda interesting to see anonymized copies of my work being sold on the Chinese second hand market, is that a life achievement unlocked? Get something you made to be copied in China?

tapsu01, 2025-06-02:
You could also consider this a success for your project, since your research genuinely brings value. But I’m still really looking forward to seeing it officially released by you.

a-little-wifi, 2025-09-28:
More of them lol

https://www.goofish.com/item?id=969058027503
https://www.goofish.com/item?id=978507511586
https://www.goofish.com/item?id=973043765599 (why?)
https://www.goofish.com/item?id=979033874891 (even more why???)

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

> removed the silkscreen logo but left the copper cat and the link to this repo on the back lol

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

> even the taco is gone

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

> I don't really get the point of this one, how was this worth changing

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

> this one raises even more questions, like, just use the stock riser???

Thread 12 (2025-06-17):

provides a PCIe x8 slot

yuntao1223, 2025-06-17:
"Hey buddy, is there an open-source version that  doesn't require an M.2 slot, but  only provides a PCIe x8 slot ? Something compatible with devices like the NEC8, Lenovo M920Q, etc. Thanks!"

yuntao1223, 2025-06-17:
> 我不确定我是否理解，你想要一个只提供PCIe x8的冒口吗？联想的标准冒口已经是这样了，如果你不需要，你甚至可以使用这种设计，而不焊接m.2插槽。

"Hi buddy, if I just remove the M.2 slot directly, is that all? Don't I need to modify anything else?"

yuntao1223, 2025-06-17:
Another question: Can the PCB layer count be reduced from 4 layers to 2 layers?

a-little-wifi, 2025-06-17:
Not installing the M.2 slot also makes C1, C2, C3, R1 and the LED useless, so those should also be left out. The PCIe x16(x8) slot will still function as usual then.
The PCB has to stay at 4 layers using the specified stackup, otherwise the impedance of the PCIe signals won't be correct and it might not work at all or with poor reliability.

yuntao1223, 2025-06-17:
This design exceeds my expectations! As a KiCad novice, I find the learning curve quite steep. Would it be possible to share the design files without the M.2 interface?

yuntao1223, 2025-06-17:
> Thanks, I worked hard on it. It takes a bit to learn but once you know how to do it it is quite fun. I don't have the time to go make specialized versions for everyone though. Either use the original Lenovo x8 one, use my design as is with the parts you don't need unsoldered or learn how to modify it yourself. If you do decide to modify the design I can review it for you if you want, to make sure it'll work.

[Tinyriser-v2.1.zip](https://github.com/user-attachments/files/20777708/Tinyriser-v2.1.zip)

Got it, thank you! I've been attempting to make these modifications myself but am unsure if I've done it correctly. I'd be truly grateful if you could review my work.

a-little-wifi, 2025-06-17:
Looks good so far, I would suggest removing TP2, TP3, TP7 and TP8 as well since their current placement doesn't make much sense with the cut down layout. There's also a few stray ground vias that aren't really necessary anymore since the PCIe lanes they relate to are gone, but leaving them doesn't hurt. You'll also need to close the edge.cuts board edge shape.
I would also appreciate it if you could put some distinguishing mark on it to show it's a modified version of the design.

a-little-wifi, 2025-06-17:
Oh I also notived the zip is called v2.1 while you seem to be using project files from v2, make sure you know which version you're using. I plan to finalize v2.1 as a release soon when I receive my next batch of boards.

yuntao1223, 2025-06-17:
> Looks good so far, I would suggest removing TP2, TP3, TP7 and TP8 as well since their current placement doesn't make much sense with the cut down layout. There's also a few stray ground vias that aren't really necessary anymore since the PCIe lanes they relate to are gone, but leaving them doesn't hurt. You'll also need to close the edge.cuts board edge shape. I would also appreciate it if you could put some distinguishing mark on it to show it's a modified version of the design.

My sincere apologies for the inconvenience. I'm currently working with the V2 design files while still learning the modification process. Next time I'll properly mark revised versions. This time, I've removed test points TP2, TP3, TP7, TP8, along with some disorganized grounding vias. Could I possibly trouble you to review these changes?

[Tinyriser-v0.1.zip](https://github.com/user-attachments/files/20779132/Tinyriser-v0.1.zip)

a-little-wifi, 2025-06-17:
I didn't mean that it was an inconvenience, I just wanted to suggest adding that. I've made some changes to the last file you uploaded, cleaned up the board outline a bit, cleaned up the copper keepout shapes and marked the unused testpoints as such on the schematic. I also added the text 'yuntao1223 short version' under the logo, but you can change that if you want to put a different name there. It should be ready to order like this.

[Tinyriser-v2-yuntao1223-short-version.zip](https://github.com/user-attachments/files/20781862/Tinyriser-v2-yuntao1223-short-version.zip)

yuntao1223, 2025-06-18:
> I didn't mean that it was an inconvenience, I just wanted to suggest adding that. I've made some changes to the last file you uploaded, cleaned up the board outline a bit, cleaned up the copper keepout shapes and marked the unused testpoints as such on the schematic. I also added the text 'yuntao1223 short version' under the logo, but you can change that if you want to put a different name there. It should be ready to order like this.
>
> [Tinyriser-v2-yuntao1223-short-version.zip](https://github.com/user-attachments/files/20781862/Tinyriser-v2-yuntao1223-short-version.zip)

Sincerely appreciate your guidance and revisions! I'm truly looking forward to the official Version 2.1v release. Thank you!

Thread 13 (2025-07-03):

Question about power

xy3, 2025-07-03:
Hi, does this board have a way to inject power? Since the pcie slot provides around 70W at maximum, I'd like an easy way to plug in some additional power. I notice this board has a connector but not sure if that is related.

I've been looking at things like 16X to 16x Risers with Molex connectors in order to inject power, but they wouldn't fit inside my build. So if your riser includes a connector already that would be perfect I think.

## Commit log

2024-04-11 Upgraded to Kicad 8, Changed compatibility text, changed mount bracket slots, updated readme
    [TinyRiser.kicad_pcb]
2024-04-11 Updated board pictures
2024-04-11 Updated schematic symbol text (and also sch to KiCad 8 ig lol)
    [TinyRiser.kicad_sch]
2024-05-03 Adding fan header (unfinished)
    [TinyRiser.kicad_pcb, TinyRiser.kicad_sch]
2024-05-03 Mostly finished fan connector implementation
    [TinyRiser.kicad_pcb, TinyRiser.kicad_sch]
2024-05-09 swapped fan header for right angle pin header
    [TinyRiser.kicad_pcb, TinyRiser.kicad_sch]
2024-05-15 Finished fan header implementation
    Somehow it doesn't feel like it's done but it is???
    [TinyRiser.kicad_pcb, TinyRiser.kicad_sch]
2024-05-15 updated pcb datecode lol
    why do i even put that on there
    [TinyRiser.kicad_pcb]
2024-05-15 Moved some silkscreen
    [TinyRiser.kicad_pcb]
2024-05-15 Moved some more silkscreen
    [TinyRiser.kicad_pcb]
2024-05-15 Moved a trace
    so many smol changes lol
    [TinyRiser.kicad_pcb]
2024-05-15 Ticked off completed todo list items, also the edge connector footprint was changed in an earlier commit but i forgot to mention it
    [TinyRiser.kicad_sch]
2024-05-15 Corrected weird 3.3V plane setting
    [TinyRiser.kicad_pcb]
2024-05-15 Fixed minor DRC errors
    [TinyRiser.kicad_pcb]
2024-05-15 unlong
    definitely not shitposting in my git repo
    [TinyRiser.kicad_pcb]
2024-05-15 merged redundant keepout zones
    [TinyRiser.kicad_pcb]
2024-06-13 a little prettier
    [TinyRiser.kicad_pcb]
2024-06-13 Adjusted edge footprint line width
    [TinyRiser.kicad_pcb]
2024-06-13 Slight silkscreen adjustments
    [TinyRiser.kicad_pcb]
2024-06-13 Fixed edge footprint origin
    [TinyRiser.kicad_pcb]
2024-07-13 Added pictures of v2 pcb assembled
2024-09-06 Moved fan header 3d model to represent real position
    [TinyRiser.kicad_pcb]
2025-01-27 Changed fan power 0R to solder jumper for easier assembly (v2.1) and added pcb ordering information
    [TinyRiser.kicad_pcb, TinyRiser.kicad_sch]
2025-01-27 updated readme for pcb order details image
2025-01-27 Increased power rail testpoint hole size and decreased screwpost hole size for better fit
    [TinyRiser.kicad_pcb, TinyRiser.kicad_sch]
2025-01-27 moved ssd power trace a little
    [TinyRiser.kicad_pcb]
2025-01-27 added note about using v2 release for pcb ordering
2025-01-29 Added v2.1 todo list to schematic
    [TinyRiser.kicad_sch]
2025-02-18 clarified led polarity on silkscreen
    [TinyRiser.kicad_pcb]
2025-02-18 starting to add smbus to fan control header
    [TinyRiser.kicad_pcb, TinyRiser.kicad_sch]
2025-02-21 Finished adding smbus to fan control header
    [TinyRiser.kicad_pcb, TinyRiser.kicad_sch]
2025-02-21 small silkscreen changes for 12V jumper
    [TinyRiser.kicad_pcb]
2025-02-22 Changed logo to v2.1
    [TinyRiser.kicad_pcb]
2025-02-22 Readme fixes, v2.1 might be done?
    [TinyRiser.kicad_pcb]
2025-03-12 Added alternative version with ssd led on the front for pcba
    [TinyRiser_frontled.kicad_pcb]
2025-04-14 Adjusted frontled via size, trace routing and resistor placement
    wow I really did that quick and sloppily last time. I still don't like this version, it looks weird, but it's a little better now at least. Sorry to anyone who already had a stencil made for the prev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
    [TinyRiser_frontled.kicad_pcb]
2025-04-14 Clarified alternative m.2 slot footprint compatibility
2025-04-15 Removed link to alternative M.2 slot with different footprint to avoid confusion
2025-05-23 Added some notes
    [TinyRiser.kicad_pcb, TinyRiser.kicad_sch]
2025-06-03 Added note to frontled version too
    [TinyRiser_frontled.kicad_pcb]
2025-06-09 gerber export stuff
    [TinyRiser.kicad_pcb]
2026-04-29 Updated parts list
    Added lcsc option for M.2 slot
2026-08-30 Added JLC Assembly files and complete part list
    Files exported using JLCPCB Tools 2026.04.03, not tested, please verify order on checkout.
    Also updated PCB file from KiCad 8 to KiCad 9
2026-08-30 Removed .csv from gitignore to include assembly production files
